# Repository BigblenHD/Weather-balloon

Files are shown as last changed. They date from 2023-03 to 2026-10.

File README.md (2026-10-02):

# Atmospheric Data Acquisition — Weather Balloon

Embedded firmware and custom PCB design for an atmospheric measurement payload, developed as a school project in Luxembourg.

**My contribution:** firmware development, PCB design and technical project delivery. The project brought together sensor integration, data logging, electronics assembly and launch preparation.

## Flight outcome

The original team log records a launch from Redange on **14 September 2024**, followed by recovery near Verdun, France, roughly two hours later. The payload, camera and SD card were recovered intact. The flight dataset is not included in this repository.

## Engineering work

- Integrated environmental and motion sensors using I²C and SPI.
- Developed Arduino sketches for individual sensor checks and combined acquisition.
- Implemented timestamped SD-card logging and LED status indications.
- Designed the data-logger schematic and board layout in EAGLE.

## Start here

| Area | Files | What to review |
| --- | --- | --- |
| Combined acquisition | [`all_in_one.ino`](Prep_launch/Module_software_tests/all_in_one/all_in_one.ino) | Environmental sensors, IMU, ozone, gamma sensor, PT100, RTC and SD integration |
| Smaller logger variant | [`Final_Code.ino`](Prep_launch/Final%20Code/Final_Code.ino) | BMP280 + MPU6050 acquisition and CSV-style logging |
| Hardware | [PCB files](Prep_launch/PCB) | EAGLE `.sch` schematic and `.brd` layout |
| Component experiments | [Module tests](Prep_launch/Module_software_tests) | Isolated checks and calibration sketches |

## Hardware and dependencies

The repository contains several hardware revisions. Select dependencies for the sketch you are examining; the sketches are not interchangeable.

| Sketch | Components / libraries |
| --- | --- |
| `all_in_one.ino` | Adafruit MS8607, Adafruit Unified Sensor, DFRobot OzoneSensor, Arduino LSM9DS1, Adafruit MAX31865, RTClib, SD, Wire and SPI; GDK101 access is implemented in the sketch |
| `Final_Code.ino` | MPU6050_light, Adafruit BMP280 and its dependencies, SD, Wire and SPI |

Use the Arduino IDE and a board core compatible with the selected hardware. Board selection, library versions, wiring and calibration must be matched to the original build; a reproducible build configuration is not yet recorded.

## Working with the code

1. Start with the individual [module tests](Prep_launch/Module_software_tests) to understand each peripheral.
2. Install the libraries used by your chosen sketch.
3. Match sensor addresses, chip-select pins and LED pins to the board schematic.
4. Open the sketch in the Arduino IDE, keeping any companion `.h` and `.cpp` files together.
5. Check serial output and SD logging on the bench before combining peripherals.

The folder name `Final Code` describes a historical revision. Its sketch uses BMP280 and MPU6050 sensors; the broader acquisition sketch lives under `Module_software_tests/all_in_one`.

## Project status

This repository preserves the project firmware and PCB sources. It includes experiments as well as integrated sketches, rather than a single packaged application. Measured sensor accuracy, exact dependency versions and flight-data analysis are not documented here.

## Team and acknowledgements

- **Ben Lies:** programming, PCB design and technical project delivery.
- **Ben Kasel:** mentoring, organisation, communication and troubleshooting.
- **Christophe Mayers:** soldering, project support and the original written project log.

The original log also mentions additional participants without naming them. This list reflects the credits currently documented in the repository.

[Original project log](https://github.com/BigblenHD/Weather-balloon/blob/688e36f4c935f01a88b4a0122774435af6ce9a63/README.md) · [Ben's portfolio](https://benlies.com)

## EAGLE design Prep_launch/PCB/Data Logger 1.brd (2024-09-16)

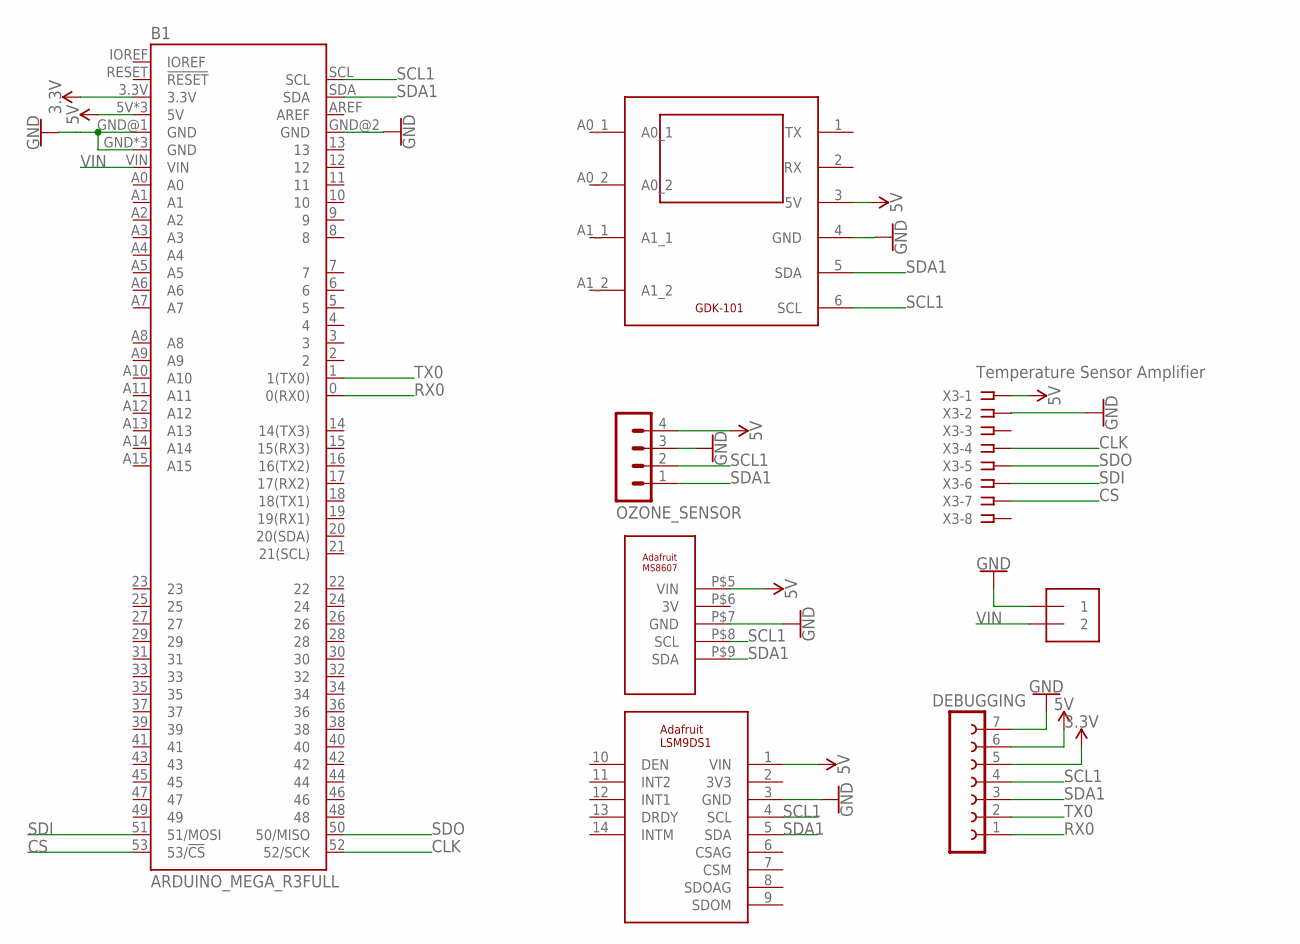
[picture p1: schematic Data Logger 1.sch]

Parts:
B1: ARDUINO_MEGA_R3FULL; ARDUINO_MEGA_NO_SILK
DEBUGGING: FE07-1; FE07
OZONE_SENSOR: OZONE_SENSOR; MA04-1
POWER_7-12V: 1X2-3.5MM
PRESSURE_SENSOR: ADAFRUIT_MS8607
U$1: FTLAB_GAMMA_SENSOR_MODULETHROUGH_HOLE; FTLAB_GAMMA_SENSOR_MODULE
U$2: ADAFRUIT_LSM9DS1
X3: Temperature Sensor Amplifier; SSW-108-02-G-S

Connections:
3.3V: B1.3.3V, DEBUGGING.5
5V: B1.5V, B1.5V@1 (5V), B1.5V@2 (5V), DEBUGGING.6, OZONE_SENSOR.4, PRESSURE_SENSOR.P$5 (VIN), U$1.3 (5V), U$2.1 (VIN), X3.1
CLK: B1.52 (52/SCK), X3.4
CS: B1.53 (53/!CS), X3.7
GND: B1.GND, B1.GND@1 (GND), B1.GND@2 (GND), B1.GND@3 (GND), B1.GND@4 (GND), DEBUGGING.7, OZONE_SENSOR.3, POWER_7-12V.1, PRESSURE_SENSOR.P$7 (GND), U$1.4 (GND), U$2.3 (GND), X3.2
RX0: B1.0 (0(RX0)), DEBUGGING.1
SCL1: B1.SCL, DEBUGGING.4, OZONE_SENSOR.2, PRESSURE_SENSOR.P$8 (SCL), U$1.6 (SCL), U$2.4 (SCL)
SDA1: B1.SDA, DEBUGGING.3, OZONE_SENSOR.1, PRESSURE_SENSOR.P$9 (SDA), U$1.5 (SDA), U$2.5 (SDA)
SDI: B1.51 (51/MOSI), X3.6
SDO: B1.50 (50/MISO), X3.5
TX0: B1.1 (1(TX0)), DEBUGGING.2
VIN: B1.VIN, POWER_7-12V.2

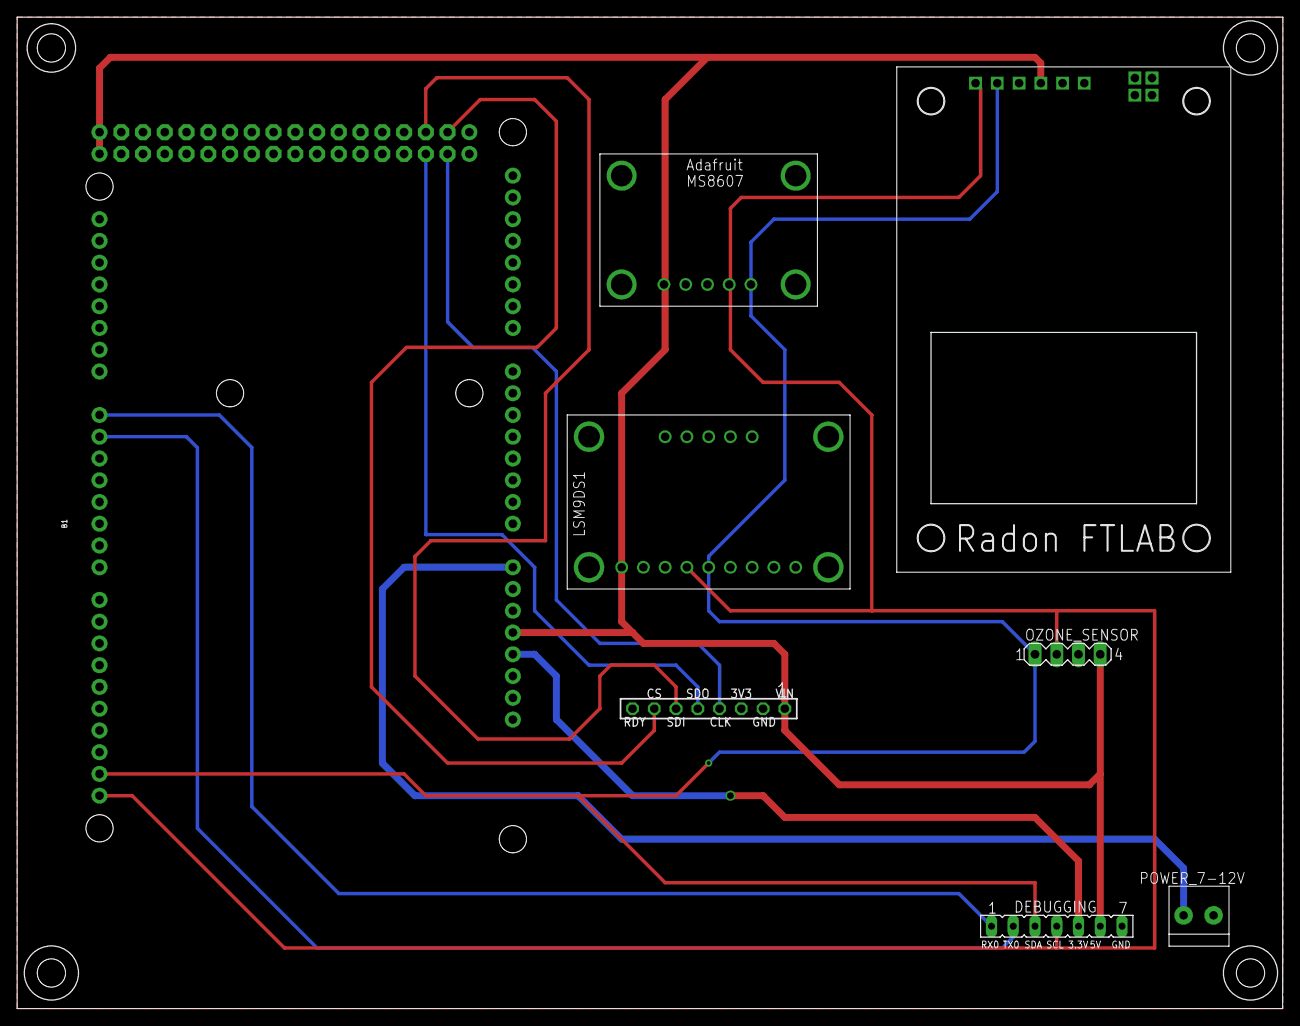
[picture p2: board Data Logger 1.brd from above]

Board: 2 copper layers, 147.8 x 115.8 mm, 8 parts (0 on the bottom side), 12 nets.

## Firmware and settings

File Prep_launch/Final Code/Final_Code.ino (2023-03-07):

#include <Wire.h>
#include <MPU6050_light.h>
#include <SPI.h>
#include <Adafruit_BMP280.h>
#include <SD.h>

MPU6050 mpu(Wire);
Adafruit_BMP280 bmp; // use I2C interface
Adafruit_Sensor *bmp_temp = bmp.getTemperatureSensor();

//definition of relevant pins for the RGB LED
#define BLUE_LED_PIN 3   //set blue LED pin
#define GREEN_LED_PIN 5 //set yellow LED pin
#define RED_LED_PIN 6   //set red LED pin

long timer = 0;
float counter = 0;
const int chipSelect = 4;

void setup() {
  Serial.begin(9600);
  pinMode(BLUE_LED_PIN, OUTPUT);
  pinMode(GREEN_LED_PIN, OUTPUT);
  pinMode(RED_LED_PIN, OUTPUT);
  digitalWrite(RED_LED_PIN, HIGH);
  // MPU60500
  Wire.begin();
  byte status = mpu.begin();
  Serial.print(F("MPU6050 status: "));
  Serial.println(status);
  while(status!=0){ } // stop everything if could not connect to MPU6050
  
  Serial.println(F("Calculating offsets, do not move MPU6050"));
  delay(1000);
  mpu.calcOffsets(true,true); // gyro and accelero
  Serial.println("Done!\n");
  
  // BMP280
  Serial.println(F("BMP280 Sensor event test"));

  //if (!bmp.begin(BMP280_ADDRESS_ALT, BMP280_CHIPID)) {
  if (!bmp.begin()) {
    Serial.println(F("Could not find a valid BMP280 sensor, check wiring or "
                      "try a different address!"));
    while (1) delay(10);
  }

  /* Default settings from datasheet. */
  bmp.setSampling(Adafruit_BMP280::MODE_NORMAL,     /* Operating Mode. */
                  Adafruit_BMP280::SAMPLING_X2,     /* Temp. oversampling */
                  Adafruit_BMP280::SAMPLING_X16,    /* Pressure oversampling */
                  Adafruit_BMP280::FILTER_X16,      /* Filtering. */
                  Adafruit_BMP280::STANDBY_MS_500); /* Standby time. */

  bmp_temp->printSensorDetails();
  
  // SD CARD READER
  while (!Serial) {
    ; // wait for serial port to connect. Needed for native USB port only
  }
  Serial.print("Initializing SD card...");

  // see if the card is present and can be initialized:
  if (!SD.begin(chipSelect)) {
    Serial.println("Card failed, or not present");
    // don't do anything more:
    while (1);
  }
  Serial.println("card initialized.");
  SD.remove("datalog.txt");
}

void loop() {
  digitalWrite(RED_LED_PIN, LOW);
  digitalWrite(GREEN_LED_PIN, HIGH);
  mpu.update();
  if(millis() - timer > 500){ // print data every second
    counter += 0.5;
    Serial.print("Seconds: ");Serial.println(counter);
    Serial.print(F("TEMPERATURE: "));Serial.println(mpu.getTemp());
    Serial.print(F("ACCELERO  X: "));Serial.print(mpu.getAccX());
    Serial.print("\tY: ");Serial.print(mpu.getAccY());
    Serial.print("\tZ: ");Serial.println(mpu.getAccZ());
  
    Serial.print(F("GYRO      X: "));Serial.print(mpu.getGyroX());
    Serial.print("\tY: ");Serial.print(mpu.getGyroY());
    Serial.print("\tZ: ");Serial.println(mpu.getGyroZ());
  
    Serial.print(F("ACC ANGLE X: "));Serial.print(mpu.getAccAngleX());
    Serial.print("\tY: ");Serial.println(mpu.getAccAngleY());
    
    Serial.print(F("ANGLE     X: "));Serial.print(mpu.getAngleX());
    Serial.print("\tY: ");Serial.print(mpu.getAngleY());
    Serial.print("\tZ: ");Serial.println(mpu.getAngleZ());
    Serial.println(F("=====================================================\n"));

    Serial.print(F("Temperature = "));
    Serial.print(bmp.readTemperature());
    Serial.println(" *C");
  
    Serial.print(F("Pressure = "));
    Serial.print(bmp.readPressure()/100);
    Serial.println(" hPa");
  
    Serial.print(F("Height = "));
    Serial.print(bmp.readAltitude() + 187.2); // 187.2 = calibration value 
    Serial.println(" m");
  
    Serial.println();

    // open the file. note that only one file can be open at a time,
    // so you have to close this one before opening another.
      File dataFile = SD.open("datalog.txt", FILE_WRITE);
    // if the file is available, write to it:
    if (dataFile) {
      dataFile.print(counter);
      dataFile.print(",");
      dataFile.print(bmp.readPressure()/100);
      dataFile.print(",");
      dataFile.print(bmp.readAltitude() + 187.2); // 187.2 = calibration value 
      dataFile.print(",");
      dataFile.print(bmp.readTemperature());
      dataFile.print(",");
      dataFile.print(mpu.getAccX());
      dataFile.print(",");
      dataFile.print(mpu.getAccY());
      dataFile.print(",");
      dataFile.print(mpu.getAccZ());
      dataFile.print(",");
      dataFile.print(mpu.getGyroX());
      dataFile.print(",");
      dataFile.print(mpu.getGyroY());
      dataFile.print(",");
      dataFile.print(mpu.getGyroZ());
      dataFile.print(",");
      dataFile.print(mpu.getAccAngleX());
      dataFile.print(",");
      dataFile.print(mpu.getAccAngleY());
      dataFile.print(",");
      dataFile.print(mpu.getAngleX());
      dataFile.print(",");
      dataFile.print(mpu.getAngleY());
      dataFile.print(",");
      dataFile.print(mpu.getAngleZ());
      dataFile.println("");
      dataFile.close();
    }
    // if the file isn't open, pop up an error:
    else {
      Serial.println("error opening datalog.txt");
      digitalWrite(GREEN_LED_PIN, LOW);
      digitalWrite(RED_LED_PIN, HIGH);
      while(1);
    }
    timer = millis();
  }
}

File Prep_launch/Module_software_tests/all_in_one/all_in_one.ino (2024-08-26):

#include <Wire.h>
#include <Adafruit_MS8607.h>
#include <Adafruit_Sensor.h>


Adafruit_MS8607 ms8607;

#include "DFRobot_OzoneSensor.h"

#include <Arduino_LSM9DS1.h>

#include <Adafruit_MAX31865.h>

#include <SPI.h>
#include <SD.h>

#include "RTClib.h"

RTC_PCF8523 rtc;

#define COLLECT_NUMBER   20              // collect number, the collection range is 1-100
#define Ozone_IICAddress OZONE_ADDRESS_3
/*   iic slave Address, The default is ADDRESS_3
       ADDRESS_0               0x70      // iic device address
       ADDRESS_1               0x71
       ADDRESS_2               0x72
       ADDRESS_3               0x73
*/
DFRobot_OzoneSensor Ozone;

int addr = 0x18;
int day,hour,min,sec = 0;
byte buffer[2] = {0,0};

int status = 0;

const int RED = 27;
const int GREEN = 25;
const int BLUE = 23;

bool ms8607_error = false;
bool ozone_sensor_error = false;
bool imu_error = false;
bool sd_error = false;
bool rtd_error = false;
bool rtc_error = false;

Adafruit_MAX31865 thermo = Adafruit_MAX31865(7, 6, 5, 4);

// The value of the Rref resistor. Use 430.0 for PT100 and 4300.0 for PT1000
#define RREF      430.0
// The 'nominal' 0-degrees-C resistance of the sensor
// 100.0 for PT100, 1000.0 for PT1000
#define RNOMINAL  100.0

const int chipSelect = 10;

File dataFile;


void setup() {
  Serial.begin(115200);
  pinMode(RED, OUTPUT);
  pinMode(GREEN, OUTPUT);
  pinMode(BLUE, OUTPUT);
  //while (!Serial) delay(10);     // will pause Zero, Leonardo, etc until serial console opens
  for(int i = 0; i< 3;i++){
     digitalWrite(GREEN, HIGH);
     delay(500);
     digitalWrite(GREEN, LOW);
     delay(500);
  }
  digitalWrite(BLUE, HIGH);
  initialize_MS8607();
  initialize_ozone();
  initialize_gamma();
  initialize_imu();
  initialize_rtd();
  initialize_sd();
  initialize_rtc();
  digitalWrite(BLUE, LOW);
  for(int i = 0; i< 3; i++){
     digitalWrite(GREEN, HIGH);
     delay(500);
     digitalWrite(GREEN, LOW);
     delay(500);
  }
}

void loop() {
  DateTime now = rtc.now();
  dataFile = SD.open("datalog.txt", FILE_WRITE);
  dataFile.print(now.toString("YYYY-MM-DD hh:mm:ss"));  dataFile.print(",");
  Serial.println("----------------------------------------------------------------");

  sensors_event_t temp, pressure, humidity;

  if(!ms8607_error){
  ms8607.getEvent(&pressure, &temp, &humidity);
  Serial.print("Temperature: ");Serial.print(temp.temperature); Serial.println(" degrees C");
  Serial.print("Pressure: ");Serial.print(pressure.pressure); Serial.println(" hPa");
  Serial.print("Humidity: ");Serial.print(humidity.relative_humidity); Serial.println(" %rH");
  Serial.println("");

  dataFile.print(temp.temperature);  dataFile.print(",");  dataFile.print(pressure.pressure);  dataFile.print(",");  dataFile.print(humidity.relative_humidity);  dataFile.print(",");
  }
  else{
    dataFile.print("nan, nan, nan");
  }
  Serial.println("----------------------------------------------------------------");
  if(!ozone_sensor_error){
  int16_t ozoneConcentration = Ozone.readOzoneData(COLLECT_NUMBER);
  Serial.print("Ozone concentration is ");
  Serial.print(ozoneConcentration);
  Serial.println(" PPB.");

  dataFile.print(ozoneConcentration);  dataFile.print(",");
  }
  else{
    dataFile.print("nan");
  }
  Serial.println("----------------------------------------------------------------");
  
  //Read Statue, Measuring Time, Measuring Value
  Gamma_Mod_Read_Value();  

  Serial.println("----------------------------------------------------------------");

  if(!imu_error){
    IMU_Data();
  }
  else{
    dataFile.print("nan, nan, nan, nan, nan, nan, nan, nan, nan");
  }

  
  Serial.println("----------------------------------------------------------------");
  if(!rtd_error){
  uint16_t rtd = thermo.readRTD();

  Serial.print("RTD value: "); Serial.println(rtd);
  float ratio = rtd;
  ratio /= 32768;
  Serial.print("Ratio = "); Serial.println(ratio,8);
  Serial.print("Resistance = "); Serial.println(RREF*ratio,8);
  Serial.print("Temperature = "); Serial.println(thermo.temperature(RNOMINAL, RREF));
  dataFile.println(thermo.temperature(RNOMINAL, RREF));

  rtd_read_reset_error();
  }
  else{
    dataFile.println("nan");
  }
  // Log data to the file
  dataFile.close();
  delay(1000);
}

void Gamma_Mod_Read_Value(){
  Gamma_Mod_Read(0xB0); // Read Status
  Gamma_Mod_Read(0xB1); // Read Measuring Time
  Gamma_Mod_Read(0xB2); // Read Measuring Value (10min avg / 1min update)
  Gamma_Mod_Read(0xB3); // Read Measuring Value (1min avg / 1min update)
}

void Gamma_Mod_Read(int cmd){
  /* Begin Write Sequence */
  Wire.beginTransmission(addr);
  Wire.write(cmd);
  Wire.endTransmission();
  /* End Write Sequence */
  delay(10);
  /* Begin Read Sequence */
  Wire.requestFrom(addr, 2);
  byte i = 0;
  while(Wire.available())
  {
    buffer[i] = Wire.read();
    i++;
  }
  /* End Read Sequence */
  
  /* View Results */
  Print_Result(cmd);
}

void Print_Result(int cmd){
  float value = 0.0f;
  switch(cmd){
    case 0xA0:
      Serial.print("Reset Response\t\t\t");
      if(buffer[0]== 1) Serial.println("Reset Success.");
      else              Serial.println("Reset Fail(Status - Ready).");
      break;
    case 0xB0:
      Serial.print("Status\t\t\t\t");
      switch(buffer[0]){
        case 0: Serial.println("Ready"); break;
        case 1: Serial.println("10min Waiting"); break;
        case 2: Serial.println("Normal"); break;
      }
      status = buffer[0];
      Serial.print("VIB Status\t\t\t");
      switch(buffer[1]){
        case 0: Serial.println("OFF"); break;
        case 1: Serial.println("ON"); break;
      }
      break;
    case 0xB1:
      if(status > 0){
        sec++;
        Cal_Measuring_Time();
      }
      break;
    case 0xB2:
      
      Serial.print("Measuring Value(10min avg)\t");
      value = buffer[0] + (float)buffer[1]/100;
      Serial.print(value); Serial.println(" uSv/hr");
      dataFile.print(value); dataFile.print(",");
      break;
    case 0xB3:
      Serial.print("Measuring Value(1min avg)\t");
      value = buffer[0] + (float)buffer[1]/100;
      Serial.print(value); Serial.println(" uSv/hr");
      dataFile.print(value); dataFile.print(",");
      break;  
    case 0xB4:
      Serial.print("FW Version\t\t\t");
      Serial.print("V"); Serial.print(buffer[0]);
      Serial.print("."); Serial.println(buffer[1]);
      break;        
  }
}

/*
 *  Calculation Measuring Time
 *  Format :: 0d 00:00:00 ( (day)d (hour):(min):(sec) )
 */
void Cal_Measuring_Time(){
  if(sec == 60)   { sec = 0;  min++;  }
  if(min == 60)   { min = 0;  hour++; }
  if(hour == 24)  { hour = 0; day++;  }

  Serial.print("Measuring Time\t\t\t");
  Serial.print(day); Serial.print("d ");
  if(hour < 10) Serial.print("0");
  Serial.print(hour); Serial.print(":");
  if(min < 10) Serial.print("0");
  Serial.print(min); Serial.print(":"); 
  if(sec < 10) Serial.print("0");
  Serial.println(sec);
}
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

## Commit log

2024-08-26 Final code
    Fixing that modules with SPI eat each other. Modules work together now. Fancy light to check initialisation. (Red is bad)
    [all_in_one.ino]
2024-09-16 Begin_of_organisation
    Structured project. Next:
    ask ben for PCB file
    revise his code
    add readme file for hardware
    [Weather Ballon Team - Tasks.xlsx]

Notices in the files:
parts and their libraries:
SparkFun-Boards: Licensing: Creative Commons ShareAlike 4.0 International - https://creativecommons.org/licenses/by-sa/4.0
